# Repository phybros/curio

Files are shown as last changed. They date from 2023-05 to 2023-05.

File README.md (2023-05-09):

# CURIO

CURIO is an ESP8266 based dev board!

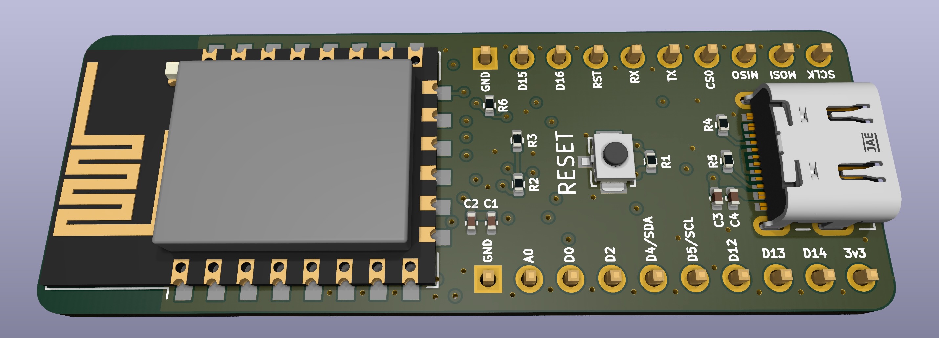
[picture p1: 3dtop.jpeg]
CURIO 3D Render


This repo is the KiCAD project for the board.

## Features

* USB-C
* ESP-12E/F WiFi module
* Compatible with Arduino
* Breadboard friendly
* Voltage divider for the `ADC0` pin

## More info

A more detailed writeup on the development of this board can be found at 
<https://willwarren.com/2023/05/09/curio-an-esp-12f-based-dev-board/>!

## License

This repo is licensed under Creative Commons Attribution-ShareAlike 4.0 
International.

Read the full license here: [LICENSE.txt](LICENSE.txt)

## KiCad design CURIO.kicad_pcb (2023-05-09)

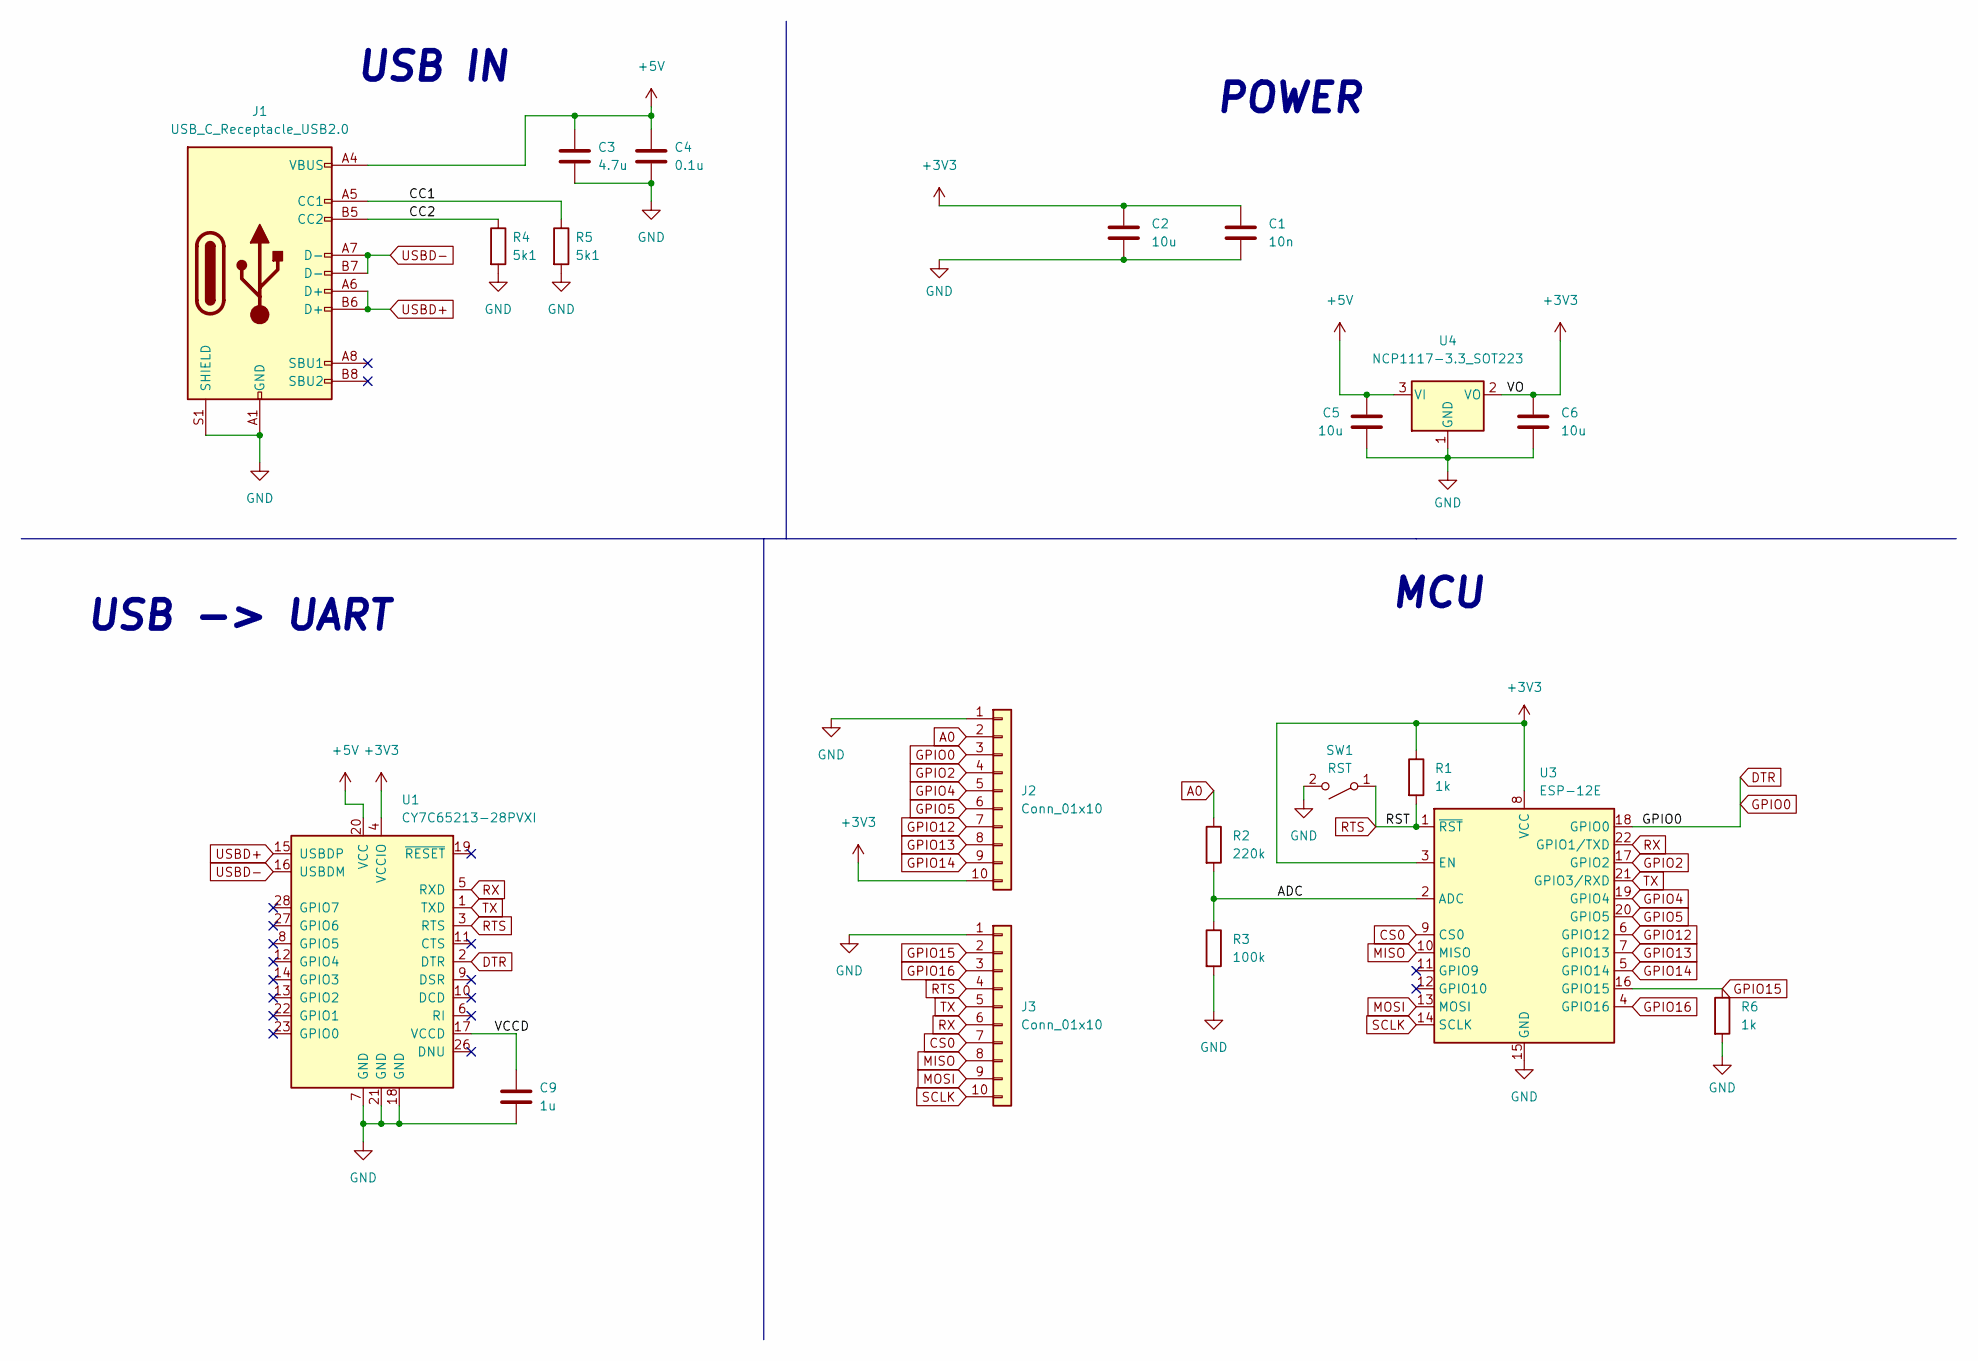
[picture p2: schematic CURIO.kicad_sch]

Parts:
C1: 10n; C_0402_1005Metric
C2, C5, C6: 10u; C_0402_1005Metric
C3: 4.7u; C_0402_1005Metric
C4: 0.1u; C_0402_1005Metric
C9: 1u; C_0402_1005Metric
J1: USB_C_Receptacle_USB2.0; USB_C_Receptacle_JAE_DX07S016JA1R1500
J2, J3: Conn_01x10; PinHeader_1x10_P2.54mm_Vertical
R1, R6: 1k; R_0402_1005Metric
R2: 220k; R_0402_1005Metric
R3: 100k; R_0402_1005Metric
R4, R5: 5k1; R_0402_1005Metric
SW1: RST; SW_SPST_B3U-1100P
U1: CY7C65213-28PVXI; SSOP-28_5.3x10.2mm_P0.65mm
U3: ESP-12E
U4: NCP1117-3.3_SOT223; SOT-223-3_TabPin2

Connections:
+3V3: C1.1, C2.1, C6.1, J2.10, R1.1, U1.4 (VCCIO), U3.3 (EN), U3.8 (VCC), U4.2 (VO)
+5V: C3.1, C4.1, C5.1, J1.A4 (VBUS), J1.A9 (VBUS), J1.B4 (VBUS), J1.B9 (VBUS), U1.20 (VCC), U4.3 (VI)
/ADC: R2.2, R3.1, U3.2 (ADC)
/CC1: J1.A5 (CC1), R5.1
/CC2: J1.B5 (CC2), R4.1
/VCCD: C9.1, U1.17 (VCCD)
A0: J2.2, R2.1
CS0: J3.7, U3.9 (CS0)
DTR: J2.3, U1.2 (DTR), U3.18 (GPIO0)
GND: C1.2, C2.2, C3.2, C4.2, C5.2, C6.2, C9.2, J1.A1 (GND), J1.A12 (GND), J1.B1 (GND), J1.B12 (GND), J1.S1 (SHIELD), J2.1, J3.1, R3.2, R4.2, R5.2, R6.2, SW1.2 (B), U1.7 (GND), U1.18 (GND), U1.21 (GND), U3.15 (GND), U4.1 (GND)
GPIO2: J2.4, U3.17 (GPIO2)
GPIO4: J2.5, U3.19 (GPIO4)
GPIO5: J2.6, U3.20 (GPIO5)
GPIO12: J2.7, U3.6 (GPIO12)
GPIO13: J2.8, U3.7 (GPIO13)
GPIO14: J2.9, U3.5 (GPIO14)
GPIO15: J3.2, R6.1, U3.16 (GPIO15)
GPIO16: J3.3, U3.4 (GPIO16)
MISO: J3.8, U3.10 (MISO)
MOSI: J3.9, U3.13 (MOSI)
RTS: J3.4, R1.2, SW1.1 (A), U1.3 (RTS), U3.1 (~RST)
RX: J3.6, U1.5 (RXD), U3.22 (GPIO1/TXD)
SCLK: J3.10, U3.14 (SCLK)
TX: J3.5, U1.1 (TXD), U3.21 (GPIO3/RXD)
USBD+: J1.A6 (D+), J1.B6 (D+), U1.15 (USBDP)
USBD-: J1.A7 (D-), J1.B7 (D-), U1.16 (USBDM)

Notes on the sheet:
USB IN
MCU
POWER
USB -> UART

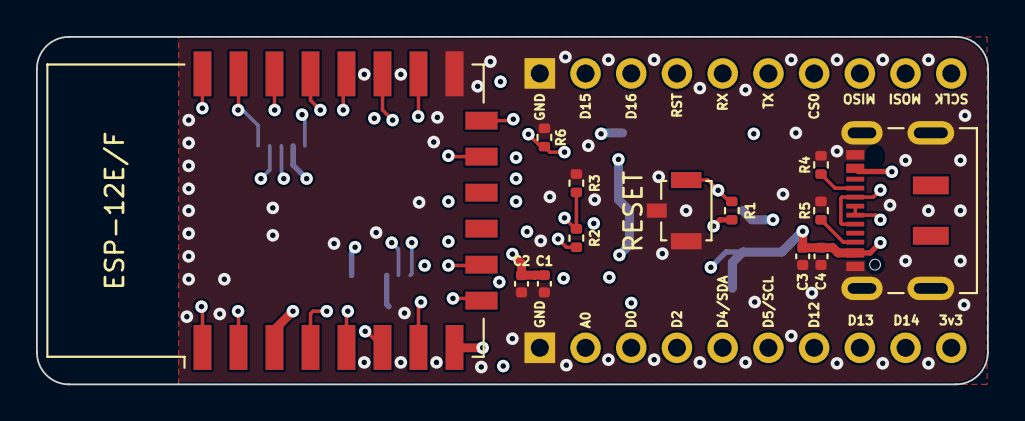
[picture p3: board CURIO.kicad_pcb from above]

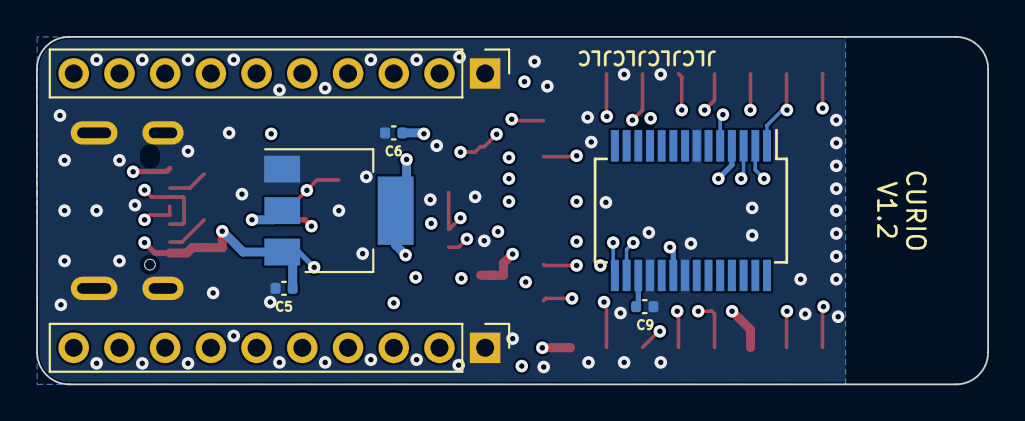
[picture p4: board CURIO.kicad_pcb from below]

Board: 4 copper layers, 52.8 x 19.3 mm, 20 parts (7 on the bottom side), 26 nets.
